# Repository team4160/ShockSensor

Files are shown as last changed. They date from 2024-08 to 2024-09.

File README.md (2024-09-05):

A shock sensor for pre-season events logging to SD card.
credit to the zebracorns:
https://github.com/FRC900/2023RobotCode/blob/main/zebROS_ws/src/adafruit_adxl37x/src/Ada_the_fruit_on_the_acceleratormator.py

We Ported it over to pico 2040, added an SD Card writer, and some LED's.
See circut diagram and case files to make and print.

The default startup is to light all lights (1-5), calculate a "Noise" threshold (2-3 lit), then wait for the first shock event (2,3,4 Lit).
This allows you to sync up multiple units all to the same "time_sync_event".
To sync them up: Put all the units on the same surface, wait till 2,3,4 are lit, then hit the surface with a hammer.
they should all go red (1) then green (5)

LED Statuses:
1 blinking fast for 10 seconds: Something wrong with SD Card.
all LED on: stuck in boot.
2&3 lit: Calculating Noise threshold
2,3,4 Lit: Waiting for First event
4 lit: Waiting for shock
1 single blink less than 2 seconds : Writing to SD card

Running on Adafruit CircuitPython 9.1.3 
Install from: https://circuitpython.org/board/raspberry_pi_pico/
Install adafruit_adxl34x.mpy and adafruit_adxl37x.mpy from the adafruit-circutpython-bundle-9.x into the lib folder of the Pico over USB.
Copy code.py over to the Pico USB drive.

Wire up according to the Impact Sensor.fzz (.png also provided).

Parts List:
SD Card: https://amzn.to/4gctrdu
SD Card Reader: https://amzn.to/3XgmkZ3
LED: https://amzn.to/3My8YCd
~200 Ohm Resistors: https://amzn.to/3AOs7gT
Pico 2040: https://www.adafruit.com/product/4864
ADXL375 Sensor: https://www.adafruit.com/product/5374

Assume that you also have wire, solder, etc..

3D printable case file supplied as well here as a .3mf file and fusion 360 source.
You'll need M2 and M3 screws for the case.

Video of it in testing:
https://youtu.be/Hgpz41B1Njg

Hopefully we can get some crash data from all your robots!

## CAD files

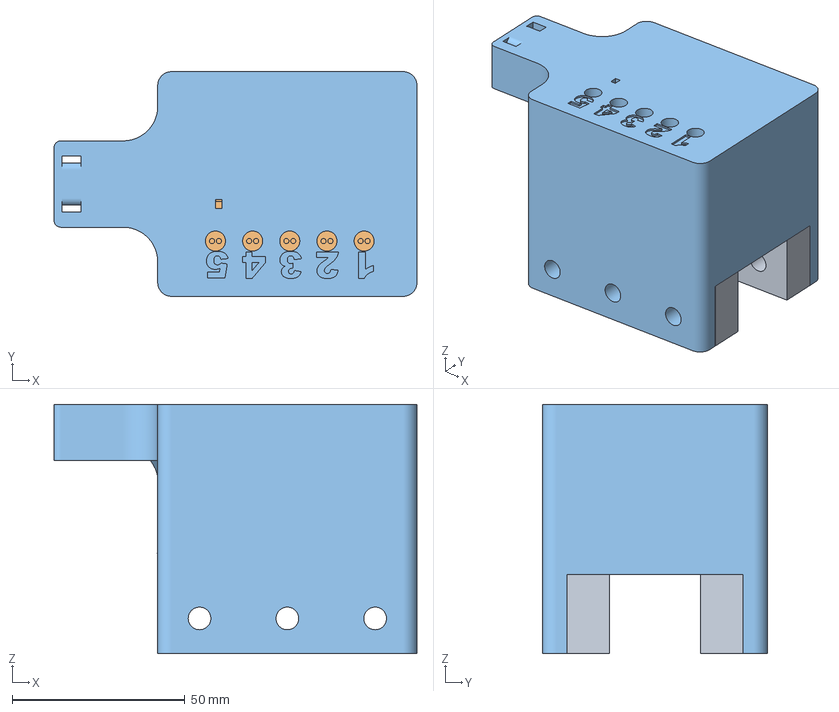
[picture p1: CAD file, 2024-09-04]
Impact Tester Case v12.3mf
105.0 x 65.0 x 72.1 mm
1 in adapterblock
Case Bottom
Case top

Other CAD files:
Impact Tester Case v12.f3z

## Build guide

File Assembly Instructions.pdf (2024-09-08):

Prior to the electronics build, put CircutPython 9.1.1 on the Pico. Copy the two library files (adafruit_adxl37x.mpy, adafruit_adxl34x.mpy) into the lib folder of the circutpython USB drive as well once it’s running Circutpython. See the instructions on https://circuitpython.org/board/raspberry_pi_pico/ for how to install CircutPython and get the 9.x libraries files (only install the 2 library files from the bundle).

1. install headers on ADXL sensor. We only need the pins on the 6 pin side.

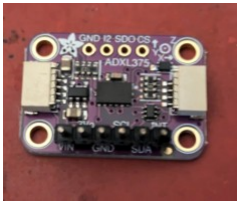
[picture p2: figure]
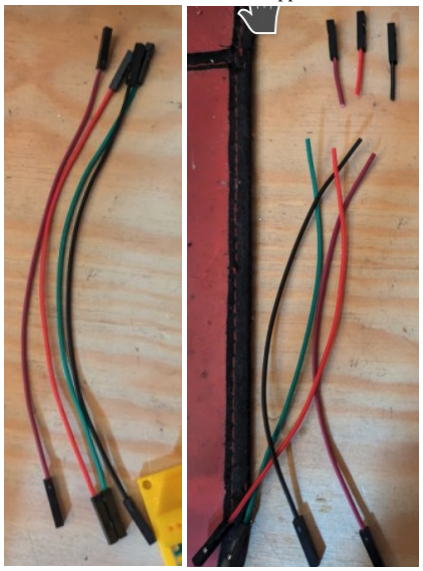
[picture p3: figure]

2. Get 4 wires for the sensor. Cut them at approx 4.5 in:

3. Get 6 wires for the SD card. Again cut at approx 4.5 in:

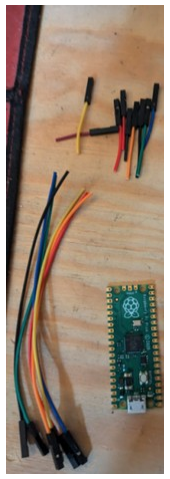
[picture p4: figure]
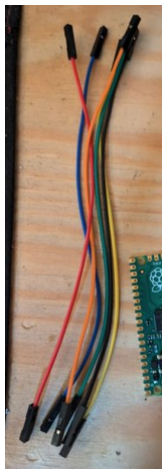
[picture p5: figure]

4. Cut 1xRed, 2x Yellow, 2x Green Wires at >.75inches, and strip off at least .25in (.5 is too much).

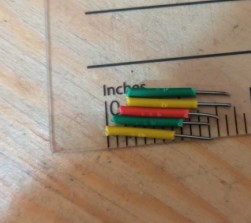
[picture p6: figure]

We will slide the insulator up and down. .25 is the minimum and 3/8ths is probably perfect.

5. Make a J at the end to hook it through the board. Do not use up all the wire for the J, just bearly enough to fit into the castelated edge. Repeat for all 5 wires. In the picture the Green wires are too short. The Yellow are perfect. See the “Wiring Diagram.png” on github for the latest.

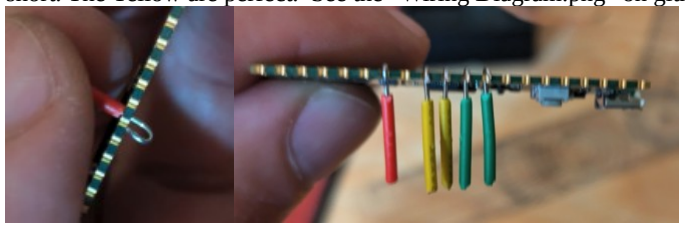
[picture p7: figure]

6. Solder wires. Then push down insulator when cool.

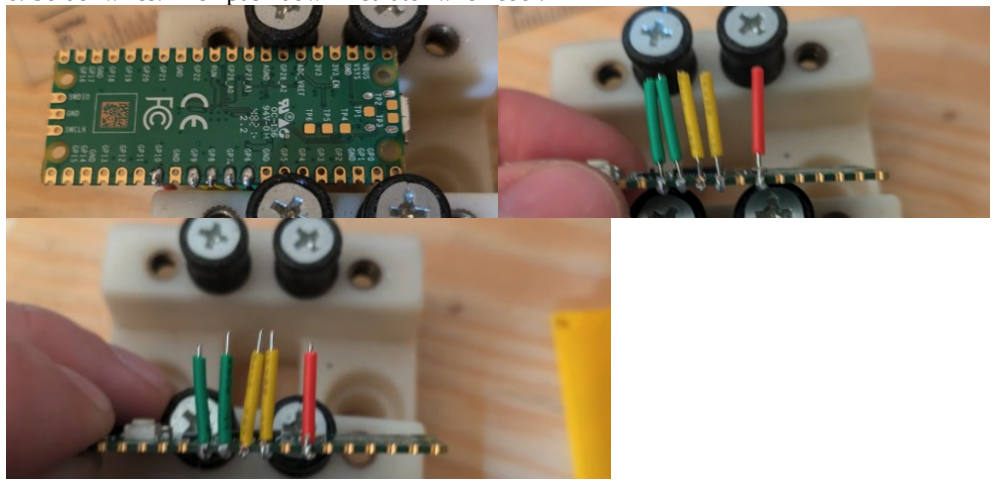
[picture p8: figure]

Note… Yellow and one Green are perfect. Red and one Green too short.

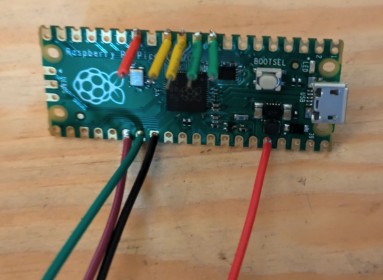
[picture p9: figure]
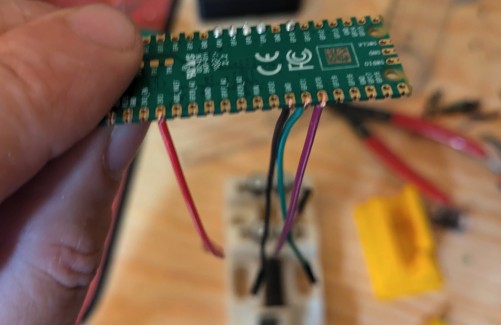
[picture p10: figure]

7. Connect Sensor Wires:
8. Repeat for SD Card Wires:

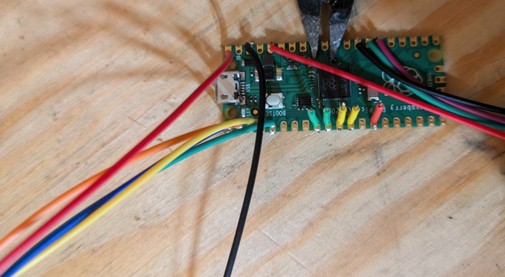
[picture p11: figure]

9. Bend and insert LED. Bend is shown with longer leg on top. Insert with longer leg to the left.

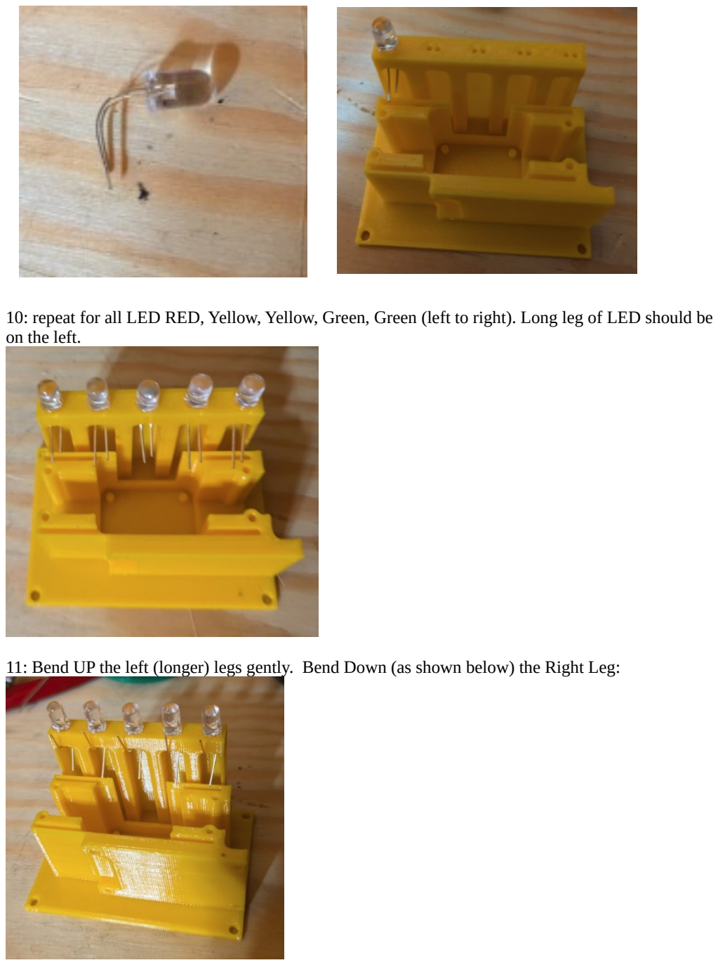
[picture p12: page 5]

10: repeat for all LED RED, Yellow, Yellow, Green, Green (left to right). Long leg of LED should be on the left.

11: Bend UP the left (longer) legs gently. Bend Down (as shown below) the Right Leg:

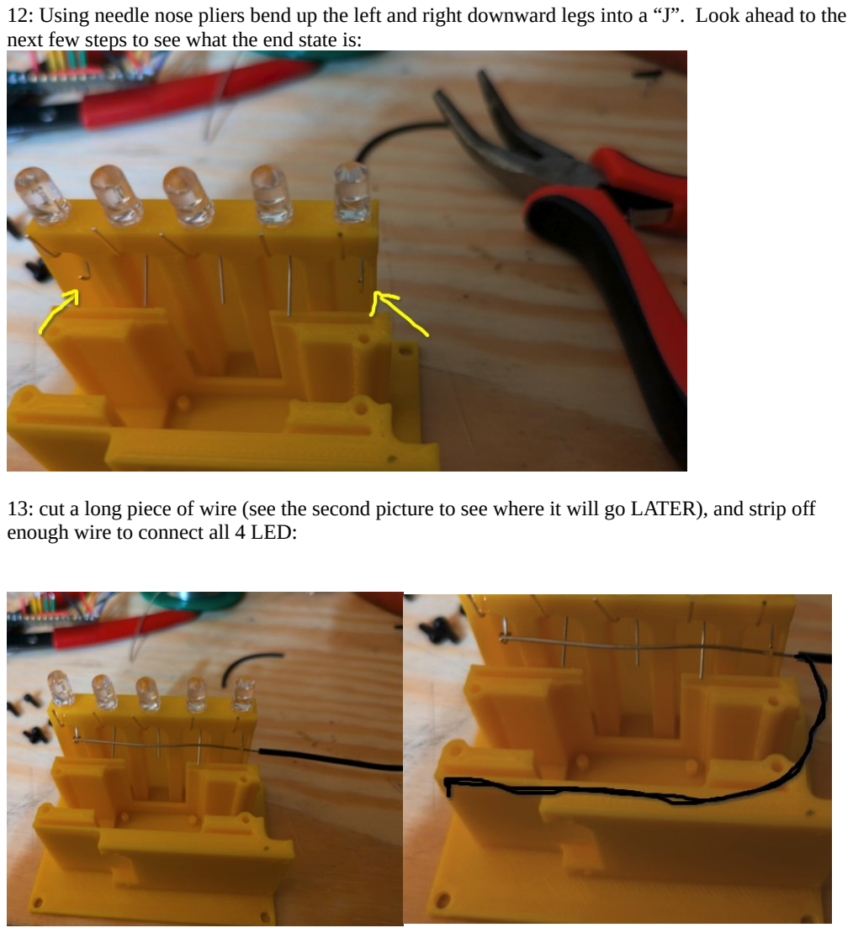
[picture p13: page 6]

12: Using needle nose pliers bend up the left and right downward legs into a “J”. Look ahead to the next few steps to see what the end state is:

13: cut a long piece of wire (see the second picture to see where it will go LATER), and strip off enough wire to connect all 4 LED:

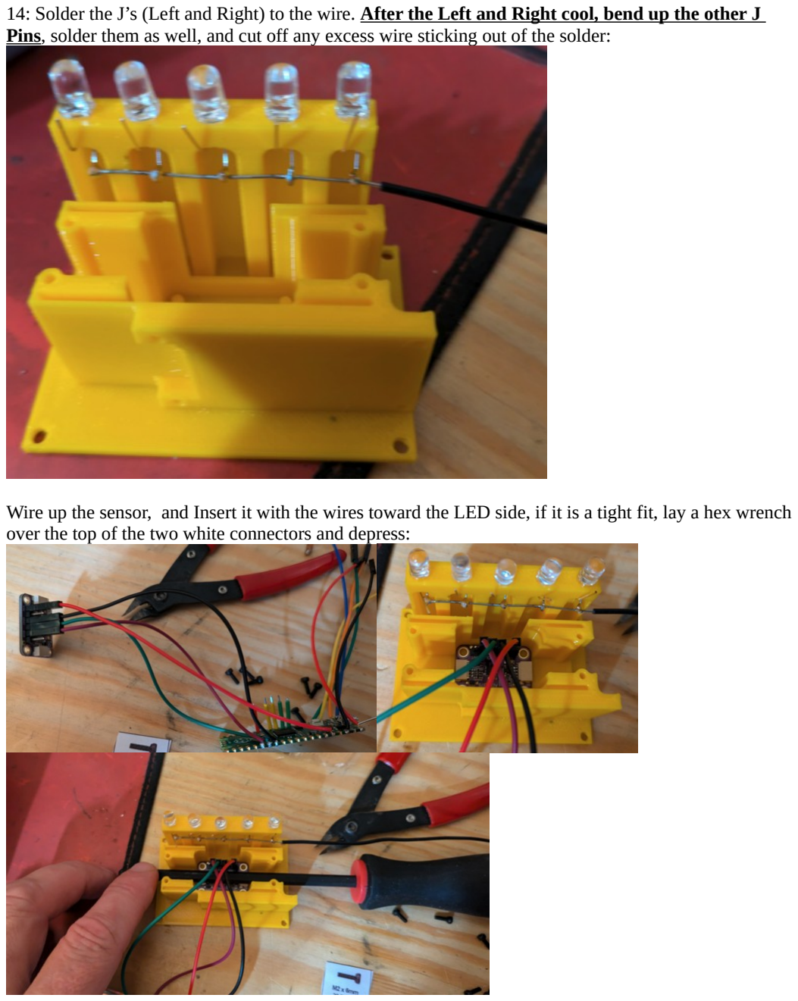
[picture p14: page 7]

14: Solder the J’s (Left and Right) to the wire. After the Left and Right cool, bend up the other J Pins, solder them as well, and cut off any excess wire sticking out of the solder:

Wire up the sensor, and Insert it with the wires toward the LED side, if it is a tight fit, lay a hex wrench over the top of the two white connectors and depress:

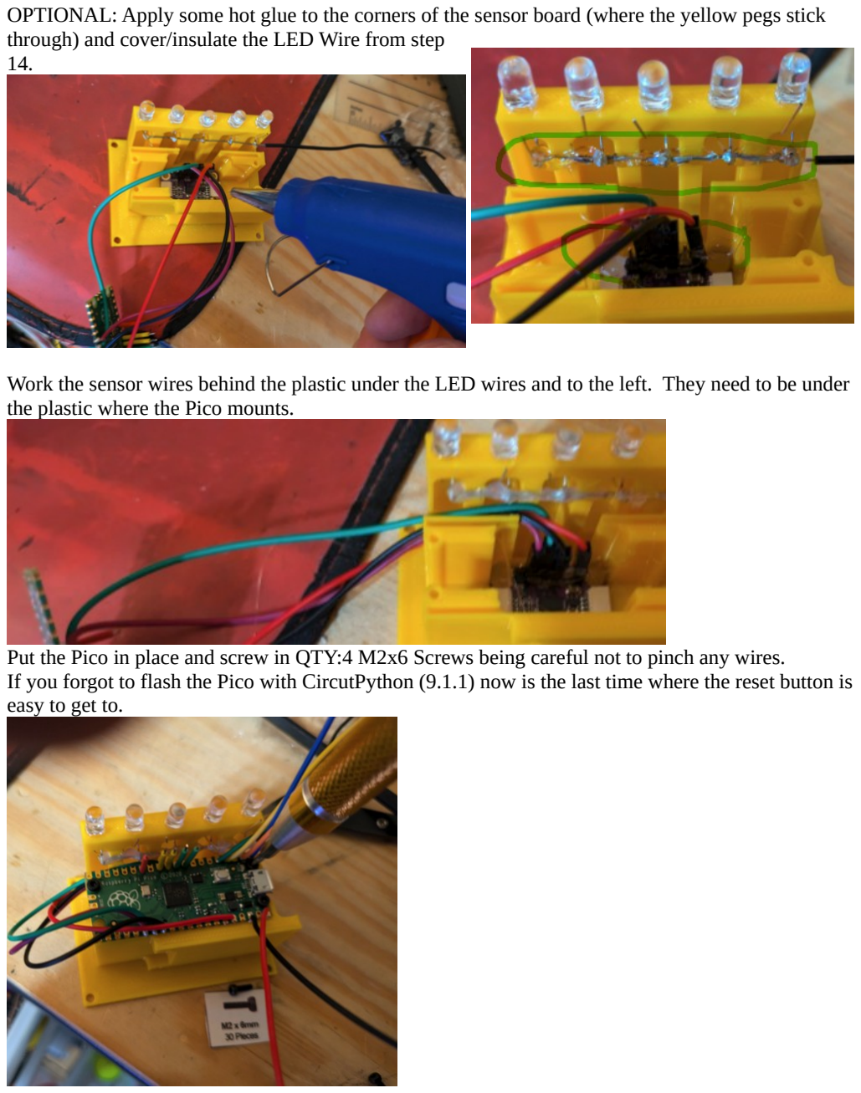
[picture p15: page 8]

OPTIONAL: Apply some hot glue to the corners of the sensor board (where the yellow pegs stick through) and cover/insulate the LED Wire from step
14.

Work the sensor wires behind the plastic under the LED wires and to the left. They need to be under the plastic where the Pico mounts.

Put the Pico in place and screw in QTY:4 M2x6 Screws being careful not to pinch any wires.
If you forgot to flash the Pico with CircutPython (9.1.1) now is the last time where the reset button is easy to get to.

If you have excess wire, you can tuck it in.

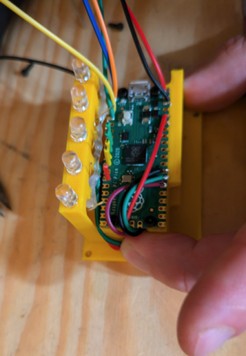
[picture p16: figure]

Wire up the SD Card. Attach it to the side with QTY:4 M2x6 Screws.

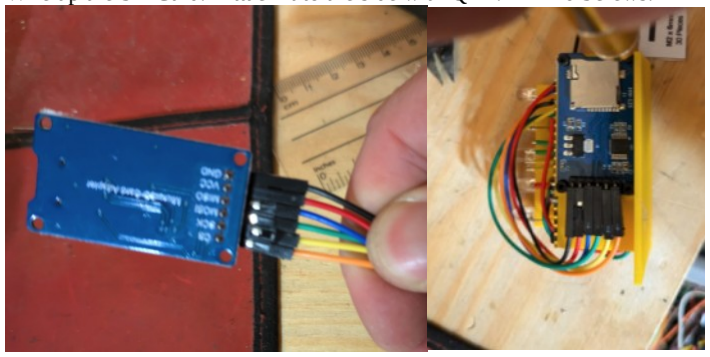
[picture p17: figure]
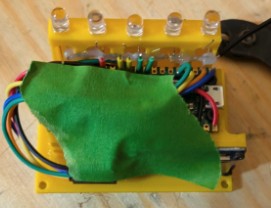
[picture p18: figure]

Put a piece of tape over the wires, this will help protect them while we wire up the LED.

Bend each resistor into a little hooked configuration (wrong value resistor shown).
Attach them between the bent up leg, and the colored wires (Red, Yellow, Green). This is the hardest step. After this things are easier..

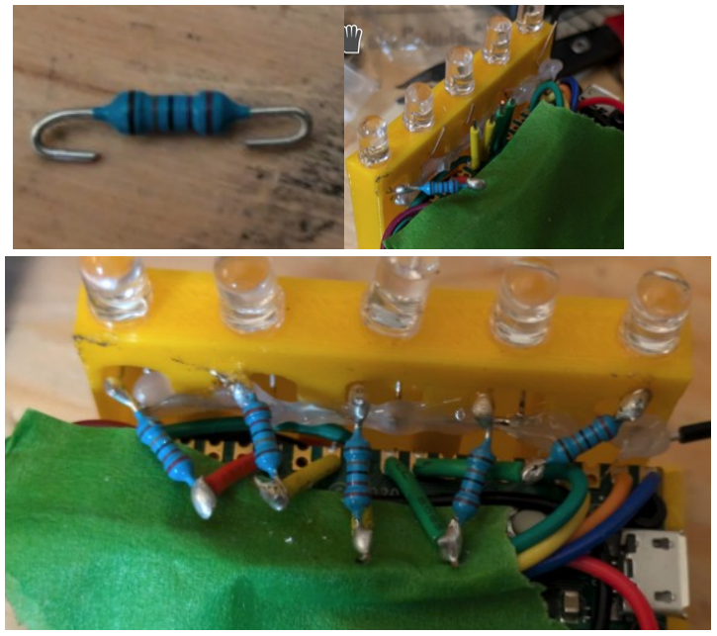
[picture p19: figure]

Apply hot glue to the resistors to insulate them from each other. Remove the tape once fully cooled.

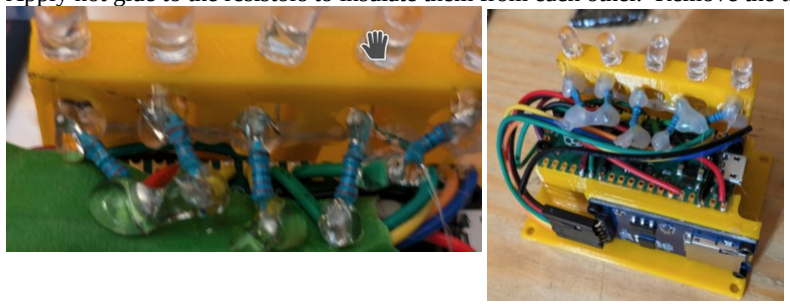
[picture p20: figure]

Before putting on the cover, insert an SD Card, and test the electronics.
Make sure that the code.py is in the root of the circutpython USB drive(not the SD Card), and that the two library files (adafruit_adxl37x.mpy, adafruit_adxl34x.mpy) are in the lib folder of the circutpython USB drive(not the SD Card). The SD card will get two files written to it if all is right. Test.txt which is just a test file that gets overwritten each power up. Data.txt which gets APPENDED to. If you want each test to have a different file then rename or move Data.txt.

Use 4x M3 screws of length >4mm <10mm to secure the cover to the base. Attach your USB cable to power it, and when ready for use zip tie it in place. Yes you can power it off of 3xAA batteries. Currently testing how long it lasts powered off AA Batteries.

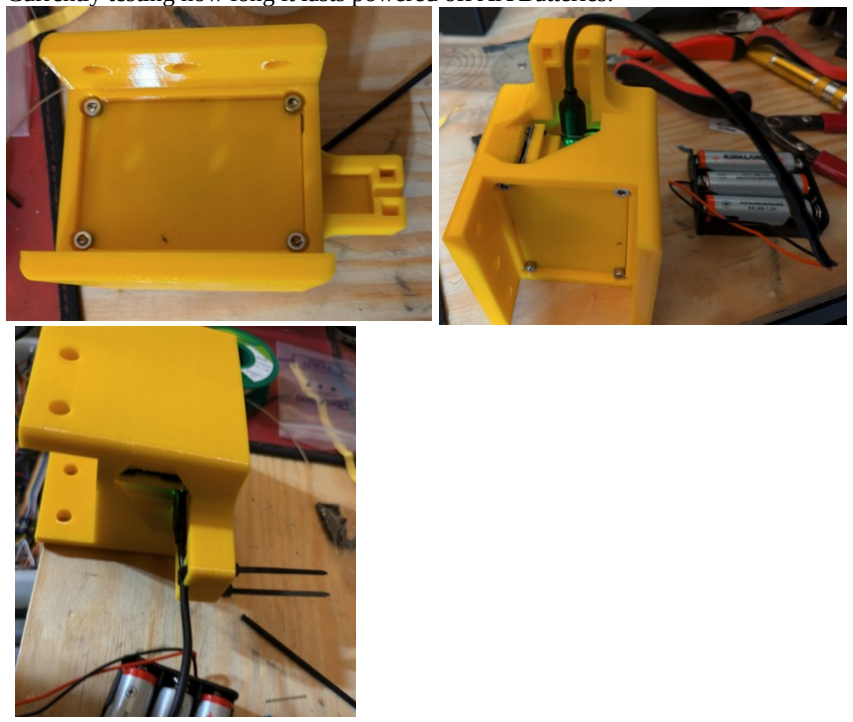
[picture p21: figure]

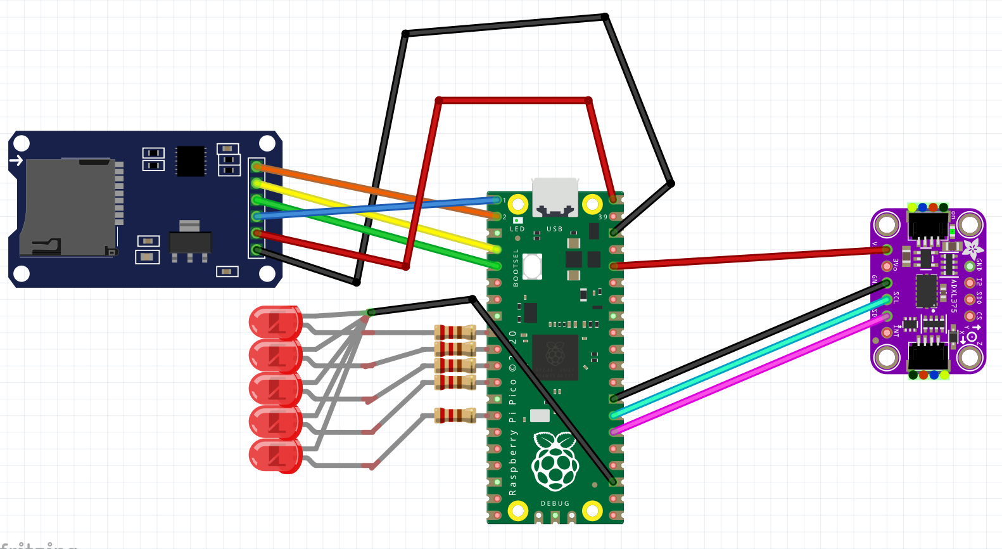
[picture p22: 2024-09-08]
Wiring Diagram.png

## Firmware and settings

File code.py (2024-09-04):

# SPDX-FileCopyrightText: 2024 Team 4160 The RoBucs with code from Team 900 The Zebracorns
#
# SPDX-License-Identifier: BSD 3-Clause License
#
# Notes and salutations
# The default startup is to light all lights (1-5), calculate a "Noise" threshold (2-3 lit), then wait for the first shock event (2,3,4 Lit).
# This allows you to sync up multiple units all to the same "time_sync_event". 
# To sync them up: Put all the units on the same surface, wait till 2,3,4 are lit, then hit the surface with a hammer.
# they should all go red (1) then green (5)

# LED Statuses:
# 1 blinking fast for 10 seconds: Something wrong with SD Card.
# all LED on: stuck in boot.
# 2&3 lit: Calculating Noise threshold
# 2,3,4 Lit: Waiting for First event
# 4 lit: Waiting for shock
# 1 single blink less than 2 seconds : Writing to SD card



import board
import busio
import sdcardio
import storage
import digitalio
import time
import adafruit_adxl37x
from adafruit_adxl34x import DataRate
import math
import gc

##
# Settings
##

# what is the initial clock
print("\nInitial Clock")
power_on_time = time.monotonic()
print(power_on_time)

#settings
samples_per_sec = 32
sample_sec = 1/samples_per_sec
baseline_samples = 64
max_samples = 60
min_threshold = 30

# Functions
def LED_on(LED_num):
    if LED_num == 1:
        LED_1.value = True
    elif LED_num == 2:
        LED_2.value = True
    elif LED_num == 3:
        LED_3.value = True
    elif LED_num == 4:
        LED_4.value = True
    elif LED_num == 5:
        LED_5.value = True
    else:
        print("invalid LED")
def LED_off(LED_num):
    if LED_num == 1:
        LED_1.value = False
    elif LED_num == 2:
        LED_2.value = False
    elif LED_num == 3:
        LED_3.value = False
    elif LED_num == 4:
        LED_4.value = False
    elif LED_num == 5:
        LED_5.value = False
    else:
        print("invalid LED")

# bps * s should be an interger
def LED_blink(LED_num, bps, s):
    for i in range(bps * s):
        LED_on(LED_num)
        time.sleep (0.5/bps)
        LED_off(LED_num)
        time.sleep (0.5/bps)

##
# Setup Devices and LED
##

# setup LED's
LED_1 = digitalio.DigitalInOut(board.GP10)
LED_1.direction = digitalio.Direction.OUTPUT
LED_2 = digitalio.DigitalInOut(board.GP9)
LED_2.direction = digitalio.Direction.OUTPUT
LED_3 = digitalio.DigitalInOut(board.GP8)
LED_3.direction = digitalio.Direction.OUTPUT
LED_4 = digitalio.DigitalInOut(board.GP7)
LED_4.direction = digitalio.Direction.OUTPUT
LED_5 = digitalio.DigitalInOut(board.GP6)
LED_5.direction = digitalio.Direction.OUTPUT
# Test all LED
print("LED ON")
for i in range(1,6):
    LED_on(i)
time.sleep(2)
for i in range(1,6):
    LED_off(i)


# setup SD card
print("Setup SD Card")

spi = busio.SPI(board.GP2, MOSI=board.GP3, MISO=board.GP0)
cs = board.GP1
# Create SD CARD object
try:
    sdcard = sdcardio.SDCard(spi, cs)
    vfs = storage.VfsFat(sdcard)
except:
    print("Maybe no SD Card?")
    LED_blink(1,10,10)

try:
    storage.mount(vfs, "/sd")
    try:
        with open("/sd/test.txt", "w") as f:
            f.write("Powered On at:{}\r\n".format(power_on_time))
            f.close()
        LED_on(2)

    except:
        print("Failed to Mount")
        LED_blink(1,10,10)
except:
    print("Failed to Mount")
    LED_blink(1,10,10)

print("Setup Accelerometer")
# setup the connection to the accelerometer device
i2c = busio.I2C(scl=board.GP21, sda=board.GP20)  # Set and define where SCL and SDA are connected.
global accelerometer
accelerometer = adafruit_adxl37x.ADXL375(i2c)
accelerometer.data_rate  = DataRate.RATE_800_HZ
_REG_DATA_FORMAT: int = 0x31
active_change = accelerometer._read_register_unpacked(_REG_DATA_FORMAT)
accelerometer._write_register_byte(_REG_DATA_FORMAT, active_change | 0b00001011) #0b00001011 comes from the adafruit arduino library linked by ty which supposedly fixes the bits at _reg_data_format for 25+ g
LED_on(3)



# calculate a baseline by sampling then calculating the acceleration vector sqrt of X^2 + y^2 + Z^2.
# multiply by a factor for what constitutes an event we want to log.
# because X, Y, Z are squared acceleration vector is always positive.

print("Calibrating a Baseline")

total_acc_vector = 0
for sample in range(1,baseline_samples):
    x,y,z = accelerometer.acceleration
    total_acc_vector = math.sqrt((x**2)+(y**2)+(z**2)) + total_acc_vector

avg_acc_vector_noise = total_acc_vector/baseline_samples
event_threshold = max( (avg_acc_vector_noise *2), min_threshold)
print("\nEvent Threshold:{}\n".format(event_threshold))
LED_on(4)
print("Waiting for first event")

x,y,z = accelerometer.acceleration
while math.sqrt((x**2)+(y**2)+(z**2)) <= event_threshold:
    time.sleep(sample_sec)
    x,y,z = accelerometer.acceleration
time_sync_event = time.monotonic()
for i in range(1,6):
    LED_off(i)

# Now we wait for an event greater than the event_threshold.
# if the event occurs then we want to capture data
print ("Wait for Event")
LED_on(5)

# Tight loop check if the vector of all x, y , z acceleration's is larger than the threshold
# if it is larger than the threshold log data points to memory
# once we log the data points to memory, stop and write them to SD card.
# also log the start and end time to the SD card. This is close enough to the event time and is the time since
# the first shock event.
# finally clear the memory and "Garbage Collect" to keep memory free

while True:
    x,y,z = accelerometer.acceleration
    if math.sqrt((x**2)+(y**2)+(z**2)) >= event_threshold:
        print("Event Start")
        LED_off(5)
        data_list =[(x,y,z)]
        for sample in range (1, max_samples):
#            print(sample)
            x,y,z = accelerometer.acceleration
            data_list.append((x,y,z))
#            print((x,y,z))
            time.sleep(sample_sec)

        #write out data to SD card.
        with open("/sd/data.txt", "a") as data_file:
            data_file.write("\nTimestamp:{}\n".format(time.monotonic()-time_sync_event))
            for line in data_list:
                data_file.write(f"{line}\n")
            data_file.write("Timestamp:{}\n".format(time.monotonic()-time_sync_event))
            data_file.close()
        del data_list
        print(gc.mem_free())
        gc.collect()
        print(gc.mem_free())
        print("Event End")
        LED_blink(1,2,0.5)
        LED_on(5)

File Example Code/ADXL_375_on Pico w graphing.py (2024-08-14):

import board
import busio
import time
import adafruit_adxl37x
from adafruit_adxl34x import DataRate

i2c = busio.I2C(scl=board.GP21, sda=board.GP20)  # Set and define where SCL and SDA are connected.
global accelerometer
accelerometer = adafruit_adxl37x.ADXL375(i2c)
accelerometer.data_rate  = DataRate.RATE_800_HZ

_REG_DATA_FORMAT: int = 0x31

#_INT_ACT: int = 0b00010000

#so this maybe?
active_change = accelerometer._read_register_unpacked(_REG_DATA_FORMAT)
#accelerometer._write_resgiter_byte(_REG_INT_ENABLE, 0x0) #disables interrupts, so that we can write new things to registers without messing other things up?
#accelerometer._write_register_byte(_REG_DATA_FORMAT, 0b00001011) #0b00001011 comes from the adafruit arduino library linked by ty which supposedly fixes the bits at _reg_data_format for 25+ g
#accelerometer._write_register_byte(_REG_DATA_FORMAT, _INT_ACT) # ACT bit
#active_change |= _INT_ACT
accelerometer._write_register_byte(_REG_DATA_FORMAT, active_change | 0b00001011) #0b00001011 comes from the adafruit arduino library linked by ty which supposedly fixes the bits at _reg_data_format for 25+ g
# playing around with sampling rates. 32 works but can be challenging to CTL-D 64 works but cant be interrupted easily, >64 needs testing and optimzation.
samples_per_sec = 64
sample_sec = 1/samples_per_sec

while True:
    x,y,z = accelerometer.acceleration
    print((x,y,z))
    time.sleep(sample_sec)

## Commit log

2024-08-14 Create ADXL_375_on Pico w graphing.py
2024-08-14 Update ADXL_375_on Pico w graphing.py
2024-08-20 Create Example Collecting Sensor data With a threshold.py
2024-09-04 Add files via upload
    Before LED Code
2024-09-04 Version 1.0
    Full of LED! Read the LED status codes in code.py
2024-09-04 Rename ADXL_375_on Pico w graphing.py to Example Code/ADXL_375_on Pico w graphing.py
    Moving to examples
2024-09-04 Rename Example Collecting Sensor data With a threshold.py to Example Code/Example Collecting Sensor data With a threshold.py
2024-09-04 Add files via upload
    Diagrams
    [Impact Sensor.fzz]
2024-09-04 Add files via upload
    Case Fusion 360
    [Impact Tester Case v12.f3z]
2024-09-04 Add files via upload
    Case for 3D printing
    [Impact Tester Case v12.3mf]
2024-09-08 Add files via upload
    fixed ground wire
2024-09-08 Add files via upload
    fix fritzing file
    [Impact Sensor.fzz]
